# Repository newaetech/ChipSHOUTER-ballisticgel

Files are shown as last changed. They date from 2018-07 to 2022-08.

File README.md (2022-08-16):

# ChipSHOUTER® CW521 Ballistic Gel

The CW521 is an Electro-Magnetic Fault Injection (EMFI) target. It is specially designed to help you understand fault injection patterns for a given tip.

It uses a large SRAM chip as a target, which has a relatively simple layout. This lets you understand how much of a given chip you are corrupting.

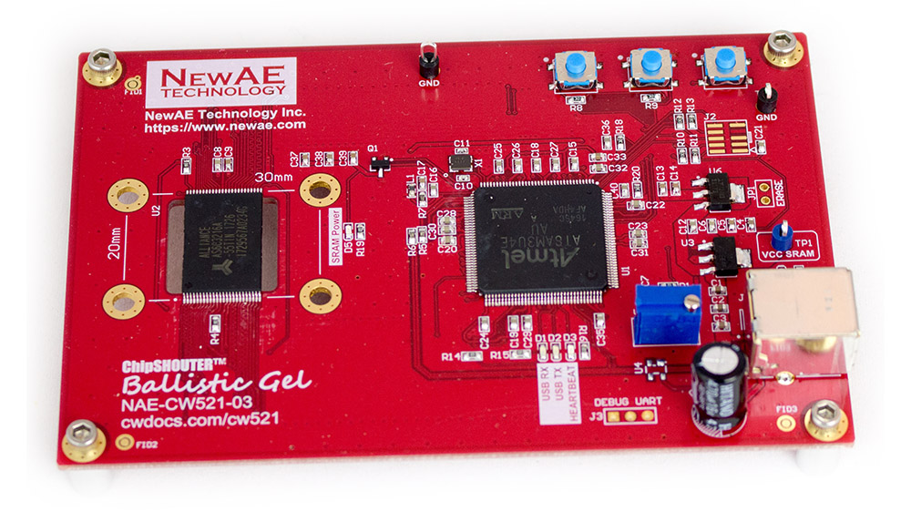
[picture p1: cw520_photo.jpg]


## GIT Layout ##

The GIT repository contains the following:

1) PCB source (Altium) + gerber files
2) Firmware for the microcontroller.
3) Python library / PC application.

## PC Application ##

The PC application is a simple example of using the Python library. This application does the following (via the library)

1. Downloads a pattern to the SRAM chip.
2. Waits for fault injection.
3. Uploads SRAM chip contents & determines corrupt locations.
4. Graphs map of physical SRAM locations (NB: not yet fully working).

The SRAM pattern can be something besides the random pattern, but the random pattern ensures "odd" corruptions (such as shorting address lines etc) will easily be caught.

An example of using the file is given at the end of ballisticgel.py, see the following:

	cw521 = CW521()
    cw521.con()
    
    doplot = False
    savefile = None
    #savefile = 'error_locations.bin' 
    
    #Raw method recommended - same speed and more flexible
    use_raw_method = True

    while True:
        try:        
            if use_raw_method:
                print "Writing data..."
                cw521.raw_test_setup()
                raw_input("Hit enter when glitch inserted")
                results = cw521.raw_test_compare()
            else:
                print "Writing data..."
                cw521.seed_test_setup()
                raw_input("Hit enter when glitch inserted")
                results = cw521.seed_test_compare()
            
            errdatay = results['errdatay']
            errdatax = results['errdatax']
            errorlist = results['errorlist']
            
            if doplot:
                plt.plot(errdatax, errdatay, '.r')
                plt.axis([0, 8192, 0, 4096])
                plt.show()

            if savefile:
                with open(savefile, "wb") as errfile:
                    errfile.write(bytearray(errorlist))
        except:
            cw521.close()

The "graph" that pops up afterwards is slightly bogus - the physical map of the SRAM is not yet accurate. But the most interesting aspect is that you can see number of bit flips (positive/negative), and total number of bytes corrupted.

### Result Format ###

The result information is provided in a dictionary. Depending if you use the fast (but less detailed) method or the slow (but more detailed) method you may not have all of these fields. It currently provides you with this:

 - 'errorlist': A list of addresses of each byte error. The length of this is the number of byte errors.
 - 'errdatax', 'errdatay': errdatax & errdatay attempt to provide a map of locations on SRAM chip where errors occurred. Until mapping is complete this is not fully accurate.
 - 'set_errors': Number of bit-set errors that occurred. Note number of bit errors is different from number of byte errors.
 - 'reset_errors': Number of bit-reset errors that occurred. Note number of bit errors is different from number of byte errors.

## Building Firmware ##

The firmware uses the ChipWhisperer capture build system (naeusb). Navigate to
`firmware/cw521` and run `git submodule update --init naeusb`. Once this has completed,
run `make`.

The firmware build requires `make` and `arm-none-eabi-gcc`.

## Drivers ##

As of commit f62ccdf0ea2d611deabf48ec3ad5db759205dbb0 and firmware version 2.0.0, 
the CW521 now uses the same WCID driver assignment as ChipWhisperer devices,
meaning no custom drivers need to be installed.

If you have old firmware/drivers and want to update, instructions
can be adapted from [ChipWhisperer's documentation on the subject](https://chipwhisperer.readthedocs.io/en/latest/drivers.html)

Note that the same `upgrade_firmware()` method is now available on the CW521 object:

```python
from ballisticgel import CW521
cw521 = CW521()
cw521.upgrade_firmware()
```

## Legal ##

Ballistic Gel is part of the ChipSHOUTER project (which is itself related to the ChipWhisperer project). It is also known as the CW521 target board.

Ballistic Gel is an open-source project, and is released with the GPL license. Assembled boards can be purchased from NewAE Technology Inc at https://store.newae.com .

ChipSHOUTER is a registered trademark of NewAE Technoloy Inc. Note you CANNOT sell boards using the ChipSHOUTER name without permission, and you cannot use NewAE Technology Inc's USB VID on your own products as the USB-IF license disallows sub-licensing in this manner. If you change the VID/PID, simply change the associated VID/PID in the .inf (driver) file as needed.

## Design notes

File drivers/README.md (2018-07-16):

# Driver Installation #

## Linux ##

 - Make a file called /etc/udev/rules.d/99-newae.rules . The contents of this file should be:
    ```
    #allow users to claim the device
    SUBSYSTEM=="usb", ATTRS{idVendor}=="2b3e", ATTRS{idProduct}=="ace1", MODE="0664", GROUP="plugdev"
    SUBSYSTEM=="usb", ATTRS{idVendor}=="2b3e", ATTRS{idProduct}=="ace2", MODE="0664", GROUP="plugdev" #CW-Lite
    SUBSYSTEM=="usb", ATTRS{idVendor}=="2b3e", ATTRS{idProduct}=="ace3", MODE="0664", GROUP="plugdev" #CW1200
    SUBSYSTEM=="usb", ATTRS{idVendor}=="2b3e", ATTRS{idProduct}=="c305", MODE="0664", GROUP="plugdev" #CW305 FPGA Target
    SUBSYSTEM=="usb", ATTRS{idVendor}=="2b3e", ATTRS{idProduct}=="c000", MODE="0664", GROUP="plugdev" #FTDI-Based JTAG Programmer
    SUBSYSTEM=="usb", ATTRS{idVendor}=="2b3e", ATTRS{idProduct}=="c521", MODE="0664", GROUP="plugdev" #CW521 Ballistic Gel
    ```
 - Add your username to the plugdev group:
    ```
    $ sudo usermod -a -G plugdev YOUR-USERNAME
    ```
 - And reset the udev system:
    ```
    $ sudo udevadm control --reload-rules
    ```

 - Finally log out & in again for the group change to take effect.

 - Connect the USB cable of your device.

## Windows ##

The attached USB drivers should work on any Windows system, both 32 and 64-bit. They are signed by NewAE Technology Inc.

We only store the **zip-file** in GIT, so you'll need to unzip it. This is done to avoid issues with line-ending changing causing the signatures to be invalid.

To install them:
 1. Unzip the zip-file somewhere. Also remember where.
 1. Open your Device Manager.
 1. Find the device in the list, it should appear with a yellow exclamation mark under "Other devices".
 1. Double-click on the device.
 1. Hit "Update Driver"
 1. Select "Browse my computer for driver software".
 1. Point the wizard to the folder you unzipped, ensure the "look in subfolders" option is selected.

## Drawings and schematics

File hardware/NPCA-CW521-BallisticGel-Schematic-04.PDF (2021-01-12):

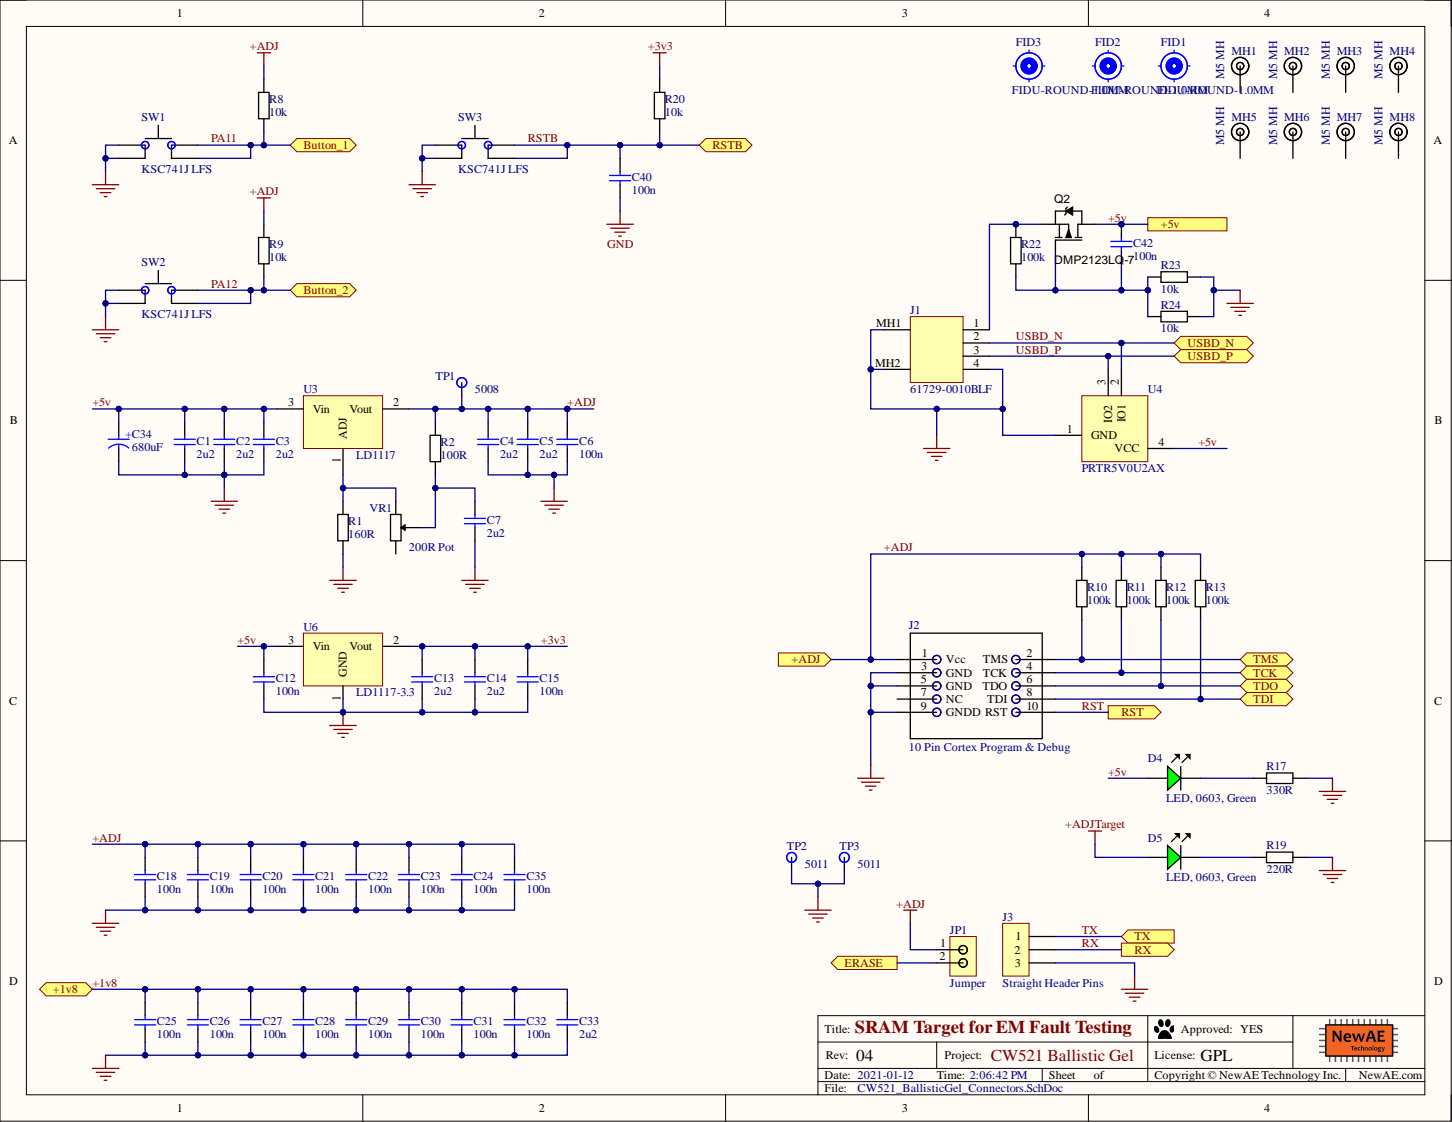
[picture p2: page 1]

10 Pin Cortex Program & Debug

SRAM Target forEM Fault Testing
Title:
Rev:
CW521_BallisticGel_Connectors.SchDoc

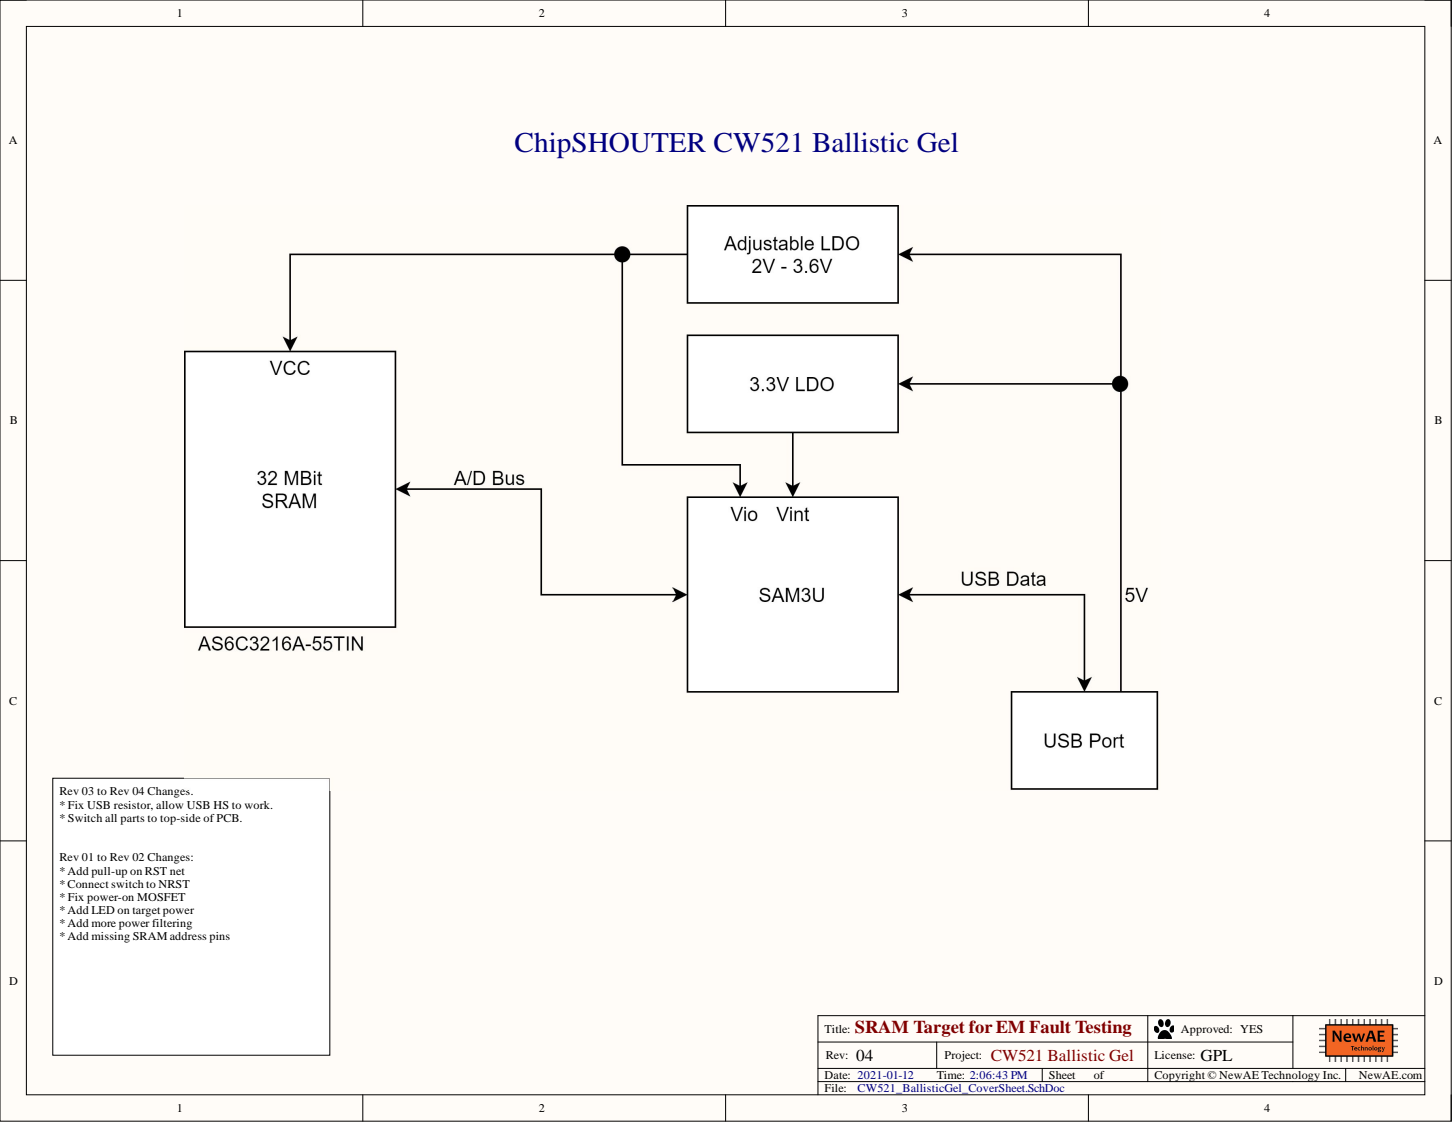
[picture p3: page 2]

Rev 03 to Rev 04 Changes:
* Fix USB resistor, allow USB HS to work.
* Switch all parts to top-side of PCB.

Rev 01 to Rev 02 Changes:
* Add pull-up on RST net
*Connectswitch to NRST
* Fix power-on MOSFET
* Add LED on target power
* Add more power filtering
* Add missing SRAM address pins

SRAM Target forEM Fault Testing

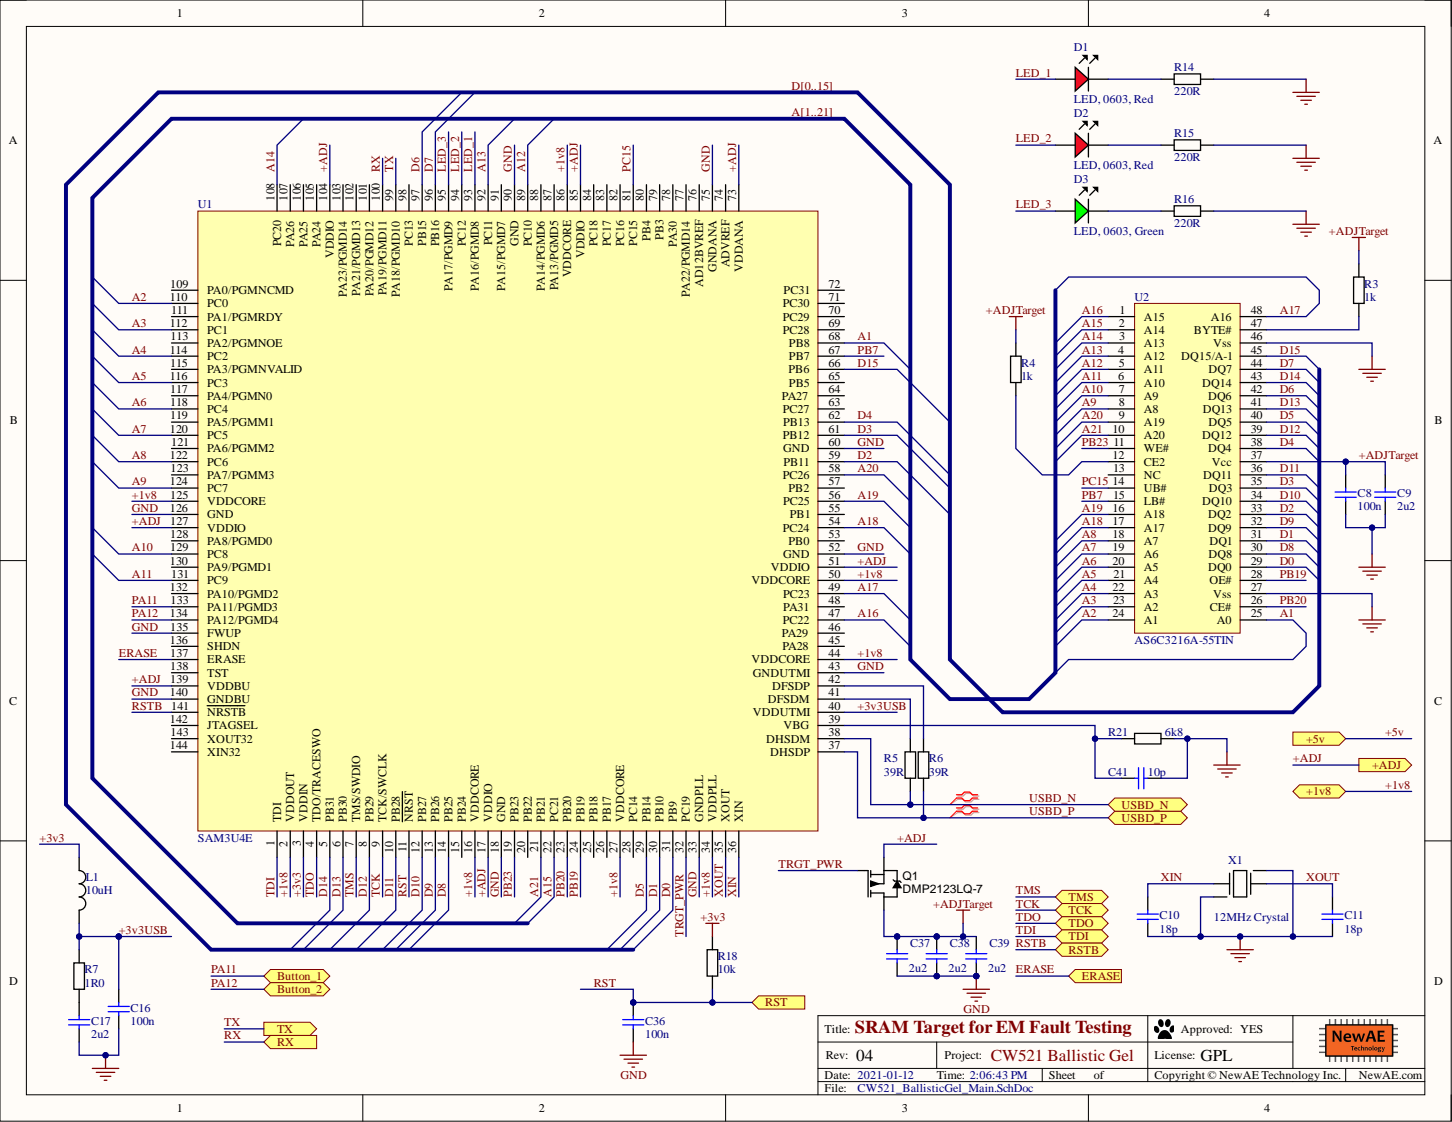
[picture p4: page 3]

VDDANA 73 ADVREF 74 GNDANA 75 AD12BVREF 76 PA22/PGMD14 77 PA30 78 PB3 79 PB4 80 PC15 81 PC16 82 PC17 83 PC18 84 VDDIO 85 VDDCORE 86 PA13/PGMD5 87 PA14/PGMD6 88 PC10 89 GND 90 PA15/PGMD7 91 PC11 92 PA16/PGMD8 93 PC12 94 PA17/PGMD9 95 PB16 96 PB15 97 PC13 98 PA18/PGMD10 99 PA19/PGMD11 100 PA20/PGMD12 101 PA21/PGMD13 102 PA23/PGMD14 103 VDDIO 104 PA24 105 PA25 106 PA26 107 PC20 108

SRAM Target forEM Fault Testing

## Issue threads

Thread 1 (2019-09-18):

python script error when reading back SRAM

doegox, 2019-09-18:
Trying the script, loading SRAM to the board worked fine, pressing Enter (without even EMFI), getting this error
```
ChipSHOUTER-ballisticgel/ballisticgel$ python ballisticgel.py
 CW521 Ballistic Gel Example Script
  by NewAE Technology Inc
 This script will continue until you exit with Ctrl-C
Settings:
  Using slow (raw) mode  : True
  Showing plot of results: False
  Results filename       : None
Starting main loop now:

LOOP START: Writing data to SRAM...
 Hit enter when glitch inserted
 Reading SRAM data...
Traceback (most recent call last):
  File "ballisticgel.py", line 329, in <module>
    results = cw521.raw_test_compare()
  File "ballisticgel.py", line 243, in raw_test_compare
    din = cw521.read_pattern()
  File "ballisticgel.py", line 102, in read_pattern
    din = self.usb.cmdReadMem(start_addr, len_to_read)
  File "/home/qb/00hardware_guilde/haqerspace/tools/chipshouter/ChipSHOUTER-ballisticgel/ballisticgel/naeusb.py", line 228, in cmdReadMem
    data = self.usbdev().read(self.rep, dlen, timeout=self._timeout)
  File "/home/phil/.local/lib/python2.7/site-packages/usb/core.py", line 988, in read
    self.__get_timeout(timeout))
  File "/home/phil/.local/lib/python2.7/site-packages/usb/backend/libusb0.py", line 542, in bulk_read
    timeout)
  File "/home/phil/.local/lib/python2.7/site-packages/usb/backend/libusb0.py", line 627, in __read
    timeout
  File "/home/phil/.local/lib/python2.7/site-packages/usb/backend/libusb0.py", line 431, in _check
    raise USBError(errmsg, ret)
usb.core.USBError: [Errno None] Connection timed out
```

colinoflynn, 2019-09-18:
Odd! We run that exact script as part of the test so the board HW *should* be fine... but I suspect it's some unknown compatibility problem.

What's your host OS?

doegox, 2019-09-18:
Linux, Debian 10.0 kernel 4.20
I poked around, if I set a large timeout on naeusb.py", line 228, the script doesn't crash but I get absurd results:
```
 Reading SRAM data...
Byte errors: 4178047 (of 4194304). Bit errors: 8387684 set (0 --> 1), 8387695 reset (1 --> 0)
```

Note that on the board, USB RX is steadily red for a while while SRAM gets loaded, but USB TX flashes only very briefly when SRAM gets read back.
So it seems that it's really the board that doesn't send much data back.

colinoflynn, 2019-09-18:
IIRC The USB TX led direction is a bit of a "bug"... the TX led gets set internally when the read-back starts, but the rest is done via DMA and it's no longer calling the USB routines for every transaction.

Also you can try switching between the "fast" and "complete" mode to see if it changes things. I'm going to try and recreate here on a Linux machine, our test machine was Windows I admit so I could have missed something there.

doegox, 2019-09-18:
about "large timeout on naeusb.py", line 228", here are some effects depending on the injected timeout:
* 0..4000 -> error
* 5000 -> absurd results, as shown above
* 6000 -> results that make sense (0 bitflip, more bitflip when EMFI)

doegox, 2019-09-18:
`use_raw_method = False` => works fine without hacking the timeout.

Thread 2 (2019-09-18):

Linux: better error handling when USB permissions problem

doegox, 2019-09-18:
On Linux, if someone forgets to install or update his /etc/udev/rules.d/99-newae.rules to include the ballisticgel VID:PID (hey what did you expect? ;) ), the python script fails with:
```
ValueError: The device has no langid
```
The error is not really helpful for someone to understand the root of the problem and the solution.
Example:
```diff
--- a/ballisticgel/naeusb.py
+++ b/ballisticgel/naeusb.py
@@ -109,7 +109,10 @@ class NAEUSB(object):
         """

         devlist = self.get_possible_devices(idProduct)
-        snlist = [d.serial_number + " (" + d.product + ")\n" for d in devlist]
+        try:
+            snlist = [d.serial_number + " (" + d.product + ")\n" for d in devlist]
+        except ValueError:
+            raise IOError("Check permissions to access the USB device")
         snlist = "".join(snlist)

```

```
$
python ballisticgel.py
 CW521 Ballistic Gel Example Script
  by NewAE Technology Inc
 This script will continue until you exit with Ctrl-C
Traceback (most recent call last):
  File "ballisticgel.py", line 306, in <module>
    cw521.con()
  File "ballisticgel.py", line 51, in con
    self.usb.con(idProduct=[usb_pid])
  File "/home/qb/00hardware_guilde/haqerspace/tools/chipshouter/ChipSHOUTER/ChipSHOUTER-ballisticgel/ballisticgel/naeusb.py", line 115, in con
    raise IOError("Check permissions to access the USB device")
IOError: Check permissions to access the USB device
```

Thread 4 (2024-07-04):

Issue calling the function usbdev() printing "Do not call me"

axelatsec, 2024-07-04:
When running ballisticgel.py in rng mode the return statement of the read function is this:

`return self.usb.usbdev().read(self.usb.rep, size, timeout=self.usb._timeout)`

and `self.usb.usbdev()` is not supposed to be called according to the function then printing "Do not call me". The code then stops functioning and doesn't complete the memory read.

alex-dewar, 2024-07-09:
Thanks for bringing this up. I'll get that fixed up.

Closed 2025-06-23.

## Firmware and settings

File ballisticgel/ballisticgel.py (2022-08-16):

# Copyright (c) 2018-2019, NewAE Technology Inc
# All rights reserved.
#
# Authors: Colin O'Flynn, Alex Dewar
#
# This file is part of the ChipSHOUTER Ballistic Gel project.
#
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
#    You should have received a copy of the GNU General Public License
#    along with this project.  If not, see <http://www.gnu.org/licenses/>.
#=============================================================================

import random

import numpy as np
import matplotlib.mlab as mlab
import matplotlib.pyplot as plt
from .ChipWhispererSAM3Update import SAMFWLoader, get_at91_ports

from . import srammap
from . import naeusb as NAE
import time
from typing import Optional, Type, Union

def program_sam_firmware(serial_port : Optional[str]=None,
    hardware_type : Optional[str]=None, fw_path : Optional[str]=None):
    """Program firmware onto an erased chipwhisperer scope or target

    See https://chipwhisperer.readthedocs.io/en/latest/firmware.html for more information

    .. versionadded:: 5.6.1
        Improved programming interface
    """
    if (hardware_type, fw_path) == (None, None):
        raise ValueError("Must specify hardware_type or fw_path, see https://chipwhisperer.readthedocs.io/en/latest/firmware.html")

    if serial_port is None:
        at91_ports = get_at91_ports()
        if len(at91_ports) == 0:
            raise OSError("Could not find bootloader serial port, please see https://chipwhisperer.readthedocs.io/en/latest/firmware.html")
        if len(at91_ports) > 1:
            raise OSError("Found multiple bootloaders, please specify com port. See https://chipwhisperer.readthedocs.io/en/latest/firmware.html")

        serial_port = at91_ports[0]
        print("Found {}".format(serial_port))
    prog = SAMFWLoader(None)
    prog.program(serial_port, hardware_type=hardware_type, fw_path=fw_path)


def packuint32(data):
    """Converts a 32-bit integer into format expected by USB firmware"""

    return [data & 0xff, (data >> 8) & 0xff, (data >> 16) & 0xff, (data >> 24) & 0xff]

class CW521(object):
    """This class defines communications with CW521 Ballistic Gel Target"""

    REQ_CHECKMEM_RNG = 0x15
    REQ_MEMWRITE_RNG = 0x14
    REQ_MEMREAD_RNG_BULK = 0x18

    sram_len = 4194304
    _hw_type = "cw521"

    def _getNAEUSB(self):
        return self.usb

    def _getCWType(self):
        return "cw521"

    def con(self, usb_vid=0x2B3E, usb_pid=0xC521):
        """Connect to the Ballistic Gel, use default VID/PID"""

        self.usb = NAE.NAEUSB()
        self.usb.con(idProduct=[usb_pid])

    def upgrade_firmware(self):
        prog = SAMFWLoader(self)
        prog.auto_program()

    def write_pattern(self, pattern):
        """Download an arbitrary pattern to the entire SRAM"""

        if len(pattern) > self.sram_len:
            raise ValueError("Length of pattern (%d) too long"%(len(pattern)))

        #Break into 1024 chunks on write - required to avoid buffer overflow!
        totalsent = 0
        chunksize = 1024
        self.usb.cmdWriteMem(0, pattern)

    def write_seed(self, seed, addr, length):
        """Write 'length' random data to 'addr', based on 'seed', done on-board
        the CW521 so faster than downloading a specific pattern.
        """
        if (len(seed) != 16):
            raise ValueError("Length of seed incorrect {}".format(len(seed)))
        pload = packuint32(length)
        pload.extend(packuint32(addr))
        pload.extend(seed)
        self.usb.sendCtrl(self.REQ_MEMWRITE_RNG, data=pload)


    def read_pattern(self, start_addr=0, len_to_read=None):
        """Read a block of data from SRAM."""

        if len_to_read is None:
            len_to_read = self.sram_len

        if len_to_read < 0:
            len_to_read = self.sram_len + len_to_read

        if (len_to_read + start_addr) > self.sram_len:
            raise ValueError("len_to_read (%d) is too long"%len_to_read)

        din = self.usb.cmdReadMem(start_addr, len_to_read)

        return din

    def read_pattern_rng(self, addr, size = 4096):
        """Read error pattern, assuming it was written using seed previously."""
        
        if size > 8192:
            raise ValueError("Read pattern too large")

        pload = packuint32(size)
        pload.extend(packuint32(addr))
        self.usb.sendCtrl(self.REQ_CHECKMEM_RNG, data=pload)
        data = self.usb.readCtrl(self.REQ_CHECKMEM_RNG, dlen = 4)
        reported_count = (data[3] << 8) | data[2]
        reported_count -= 1
        
        # Check if any errors reported - if not we return a null pattern array without needing to do
        # USB transfers at all
        if data[0] == 0:
            return [0] * size
        else:
            #Uncomment this to get details on-the-fly
            #print "Error in block {} ({}) (addr = {}, size = {})".format(addr / size, reported_count, addr, size)
            cmd = self.REQ_MEMREAD_RNG_BULK
            pload = packuint32(size)
            pload.extend(packuint32(addr))
            self.usb.sendCtrl(cmd, data=pload)
            return self.usb.usbdev().read(self.usb.rep, size, timeout=self.usb._timeout)

    def close(self):
        self.usb.close()


    def get_xor_sram(self, sram_len):
        data = np.random.randint(0, 256, sram_len)
        print("Generating xor")
        for i in range(sram_len / 4):
            if (not (i % 10000)):
                print("Done {}".format(i))
            rng_val = xorshift128()
            for j in range(4):
                data[i * 4 + j] = (rng_val >> (8 * j)) & 0xFF
        return data
               
    def seed_test_setup(self, seed=0xFAA2):
        """Setup the SRAM using a seed, target pattern generation is done on-device.
        After a fault is inserted, call seed_test_compare() to find fault numbers and
        locations."""
    
        state = []
        for i in range(0, 4):
            state.extend(packuint32(seed))
            
        self.block_size = 8192
        #time1 = time.clock()

        # Have to do one extra?
        for i in range(int(self.sram_len / self.block_size) + 1):
            self.write_seed(state, i * self.block_size, self.block_size)
        # self.write_pattern(data)
        #time2 = time.clock()
        #write_time = time2 - time1

        #Generate random test vector (so when re-run know if write was working)
        # print "Generating test vector %d bytes"%self.sram_len

        # time1 = time.clock()
        # data = get_xor_sram(self.sram_len)
        # time2 = time.clock()
        # pattern_time = time2 - time1
        
        
    def seed_test_compare(self):
        """Test the SRAM for faults, assuming it was previously setup with seed_test_setup()"""

        #time1 = time.clock()
        errorlist = []
        for i in range(0, int(self.sram_len / self.block_size)):
            errorlist.extend(self.read_pattern_rng(i * self.block_size, self.block_size))
        #time2 = time.clock()
        #read_time = time2 - time1

        test_len = self.sram_len
        #time1 = time.clock()
        byte_errors = 0
        for i in range(0, len(errorlist)):
            if not errorlist[i] == 0:
                byte_errors += 1

        #time2 = time.clock()
        #check_time = time2 - time1

        print("Byte errors: {}".format(byte_errors))
        #print "Write: {}, Read: {}, Check: {}".format(write_time, read_time, check_time)

        #print "Getting actual glitch locations in SRAM"
        sram = srammap.SRAMMapping()
        errdatax = []
        errdatay = []
        pone = False
        for i in range(0, 2**22, 2):
            err = errorlist[i] | errorlist[i + 1]

            if err > 0:
                locs = sram.get_bit_locations(i >> i)
                x = locs[0]
                ybitarray = locs[1]
                for bnum in range(0, 16):
                    if err & (1<<bnum):
                        errdatax.append(x)
                        errdatay.append(ybitarray[bnum])

        return {'errorlist':np.array(errorlist, dtype=np.uint8), 'errdatax':np.array(errdatax, dtype=np.uint8), 
                'errdatay':np.array(errdatay, dtype=np.uint8)}

    def raw_test_setup(self):
        """Download a raw pattern to the SRAM, slower than the seed method but
        allows arbitrary patterns. After inserting a fault test the pattern with
        raw_test_compare()"""

        #Generate random test vector (so when re-run know if write was working)
        #print "Generating test vector %d bytes"%self.sram_len

        #time1 = time.clock()
        self.data = np.random.randint(0, 256, self.sram_len, dtype=np.uint8)
        #time2 = time.clock()
        #pattern_time = time2 - time1

        #print "Writing..."
        #time1 = time.clock()
        self.write_pattern(self.data)
        #time2 = time.clock()
        #write_time = time2 - time1

        return
        
    def raw_test_compare(self):
        """Check the SRAM for faults based on a raw pattern previously downloaded
        with raw_test_setup()"""

        #time1 = time.clock()
        din = self.read_pattern()
        din = np.array(din, dtype=np.uint8)
        #time2 = time.clock()
        #read_time = time2 - time1

        errorcnt = 0

        errorlist = []
        set_errors = []
        reset_errors = []

        test_len = self.sram_len

        #time1 = time.clock()
        diff_list = self.data ^ din

        def np_hamming(arr):
            hw_arr = np.zeros(np.shape(arr), dtype=np.uint8)
            for i in range(8):
                hw_arr += (arr & (1 << i)) >> i
            return hw_arr

        errorlist = np_hamming(diff_list)
        set_errors = np_hamming(diff_list & ~self.data)
        reset_errors = np_hamming(diff_list & self.data)
            
        # for i in range(0, test_len):
        #     if self.data[i] != din[i]:

        #         diff = self.data[i] ^ din[i]
        #         errorlist.append(bin(diff).count('1'))
        #         set_errors.append(bin(diff & self.data[i]).count('1'))
        #         reset_errors.append(bin(diff & ~self.data[i]).count('1'))
        #         if bin(diff & ~self.data[i]).count('1') > 8:
        #             print("BULLSHIT DETECTED")
        #         errorcnt += 1
        #     else:
        #         errorlist.append(0)
        #time2 = time.clock()
        #check_time = time2 - time1

        total_set_errors = np.sum(set_errors, dtype=np.uint32)
        total_reset_errors = np.sum(reset_errors, dtype=np.uint32)

        print("Byte errors: %d (of %d). Bit errors: %d set (0 --> 1), %d reset (1 --> 0)"%(errorcnt, test_len, total_set_errors, total_reset_errors))
        #print " Timing: pattern: {}, Write: {}, Read: {}, Check: {}".format(pattern_time, write_time, read_time, check_time)

        errdatax = []
        errdatay = []
        if errorcnt > 0:
            sram = srammap.SRAMMapping()
            pone = False

            for i in range(0, 2**22, 2):
                err = errorlist[i] | errorlist[i + 1]
                if err > 0:
                    #SAM3U to SRAM mapping has A1 mapped to A0 etc, so need to account
                    #for addressing used here
                    locs = sram.get_bit_locations(i >> 1)
                    x = locs[0]
                    ybitarray = locs[1]

                    for bnum in range(0, 16):
                        if err & (1<<bnum):
                            errdatax.append(x)
                            errdatay.append(ybitarray[bnum])


        return {'errorlist':errorlist, 'errdatax':errdatax, 'errdatay':errdatay, 'set_errors':set_errors, 'reset_errors':reset_errors}

if __name__ == "__main__":

    print(" CW521 Ballistic Gel Example Script ")
    print("  by NewAE Technology Inc")
    print(" This script will continue until you exit with Ctrl-C")
    
    cw521 = CW521()
    cw521.con()
    
    doplot = False
    savefile = None
    #savefile = 'error_locations.bin' 
    
    #Raw method is slower but more flexible
    use_raw_method = False

    print("Settings: ")
    print("  Using slow (raw) mode  : " + str(use_raw_method))
    print("  Showing plot of results: " + str(doplot))
    print("  Results filename       : " + str(savefile))

    print("Starting main loop now: \n")
    
    while True:
        try:        
            if use_raw_method:
                print("LOOP START: Writing data to SRAM...")
                cw521.raw_test_setup()
                input(" Hit enter when glitch inserted")
                print(" Reading SRAM data...")
                results = cw521.raw_test_compare()
            else:
                print("LOOP START: Writing data to SRAM...")
                cw521.seed_test_setup()
                input(" Hit enter when glitch inserted")
                print(" Reading SRAM data...")
                results = cw521.seed_test_compare()
            
            errdatay = results['errdatay']
            errdatax = results['errdatax']
            errorlist = results['errorlist']
            
            if doplot:
                plt.plot(errdatax, errdatay, '.r')
                plt.axis([0, 8192, 0, 4096])
                plt.show()

            if savefile:
                with open(savefile, "wb") as errfile:
                    errfile.write(bytearray(errorlist))

            print("")
        
        except:
            cw521.close()
            raise

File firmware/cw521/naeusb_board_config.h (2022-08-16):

/**
 * \file
 *
 * \brief SAM3U-EK Board Definition.
 *
 * Copyright (c) 2011 - 2013 Atmel Corporation. All rights reserved.
 *
 * \asf_license_start
 *
 * \page License
 *
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
 * 3. The name of Atmel may not be used to endorse or promote products derived
 *    from this software without specific prior written permission.
 *
 * 4. This software may only be redistributed and used in connection with an
 *    Atmel microcontroller product.
 *
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
 * \asf_license_stop
 *
 */

#ifndef _SAM3U_EK_H_
#define _SAM3U_EK_H_

#include "compiler.h"
#include "system_sam3u.h"
#include "exceptions.h"

/*----------------------------------------------------------------------------*/
/**
 *  \page sam3u_ek_opfreq SAM3U-EK - Operating frequencies
 *  This page lists several definition related to the board operating frequency
 *
 *  \section Definitions
 *  - \ref BOARD_FREQ_*
 *  - \ref BOARD_MCK
 */

/** Board oscillator settings */
#define BOARD_FREQ_SLCK_XTAL        (0U)
#define BOARD_FREQ_SLCK_BYPASS      (0U)
#define BOARD_FREQ_MAINCK_XTAL      (12000000U)
#define BOARD_FREQ_MAINCK_BYPASS    (12000000U)

/** Master clock frequency */
#define BOARD_MCK                   CHIP_FREQ_CPU_MAX

/** board main clock xtal startup time */
#define BOARD_OSC_STARTUP_US   15625

/*----------------------------------------------------------------------------*/
/**
 * \page sam3u_ek_board_info SAM3U-EK - Board informations
 * This page lists several definition related to the board description.
 *
 * \section Definitions
 * - \ref BOARD_NAME
 * - \ref sam3uek
 * - \ref sam3u
 * - \ref cortexm3
 */

/** Name of the board */
#define BOARD_NAME "ChipWhisperer-CW521"
/** Board definition */
#define cw521
/** Family definition (already defined) */
#define sam3u
/** Core definition */
#define cortexm3

/*----------------------------------------------------------------------------*/
//! Pins ADC
#define PINS_ADC12B_TRIG  PIO_PA2_IDX
#define PINS_ADC12B_TRIG_FLAG  (PIO_PERIPH_B | PIO_DEFAULT)
#define PINS_ADC_TRIG  PIO_PA17_IDX
#define PINS_ADC_TRIG_FLAG  (PIO_PERIPH_B | PIO_DEFAULT)

//! UART pins (UTXD0 and URXD0) definitions, PA9,10.
#define PINS_UART       (PIO_PA11A_URXD | PIO_PA12A_UTXD)
#define PINS_UART_FLAGS (PIO_PERIPH_A | PIO_DEFAULT)

#define PINS_UART_MASK PIO_PA11A_URXD|PIO_PA12A_UTXD
#define PINS_UART_PIO PIOA
#define PINS_UART_ID ID_PIOA
#define PINS_UART_TYPE PIO_PERIPH_A
#define PINS_UART_ATTR PIO_DEFAULT

#define FPGA_ALE_GPIO		 (PIO_PB21_IDX)
#define FPGA_ALE_FLAGS		 (PIO_TYPE_PIO_OUTPUT_1 | PIO_DEFAULT)

/** EBI Data Bus pins */
#define PIN_EBI_DATA_BUS_D0        PIO_PB9_IDX
#define PIN_EBI_DATA_BUS_D1        PIO_PB10_IDX
#define PIN_EBI_DATA_BUS_D2        PIO_PB11_IDX
#define PIN_EBI_DATA_BUS_D3        PIO_PB12_IDX
#define PIN_EBI_DATA_BUS_D4        PIO_PB13_IDX
#define PIN_EBI_DATA_BUS_D5        PIO_PB14_IDX
#define PIN_EBI_DATA_BUS_D6        PIO_PB15_IDX
#define PIN_EBI_DATA_BUS_D7        PIO_PB16_IDX
#define PIN_EBI_DATA_BUS_D8        PIO_PB25_IDX
#define PIN_EBI_DATA_BUS_D9        PIO_PB26_IDX
#define PIN_EBI_DATA_BUS_D10        PIO_PB27_IDX
#define PIN_EBI_DATA_BUS_D11        PIO_PB28_IDX
#define PIN_EBI_DATA_BUS_D12        PIO_PB29_IDX
#define PIN_EBI_DATA_BUS_D13        PIO_PB30_IDX
#define PIN_EBI_DATA_BUS_D14        PIO_PB31_IDX
#define PIN_EBI_DATA_BUS_D15        PIO_PB6_IDX

#define PIN_EBI_DATA_BUS_FLAG1   PIO_PERIPH_A | PIO_PULLUP
#define PIN_EBI_DATA_BUS_FLAG2   PIO_PERIPH_B | PIO_PULLUP

/* NBS0 = A0 = LB# */
/* NBS1      = UB# */
#define PIN_EBI_ADDR_BUS_NBS0 PIO_PB7_IDX
#define PIN_EBI_ADDR_BUS_NBS1 PIO_PC15_IDX

#define PIN_EBI_ADDR_BUS_FLAG1  PIO_PERIPH_B | PIO_PULLUP
#define PIN_EBI_ADDR_BUS_FLAG2  PIO_PERIPH_A | PIO_PULLUP

#define PIN_EBI_ADDR_BUS_A0        PIO_PB7_IDX
#define PIN_EBI_ADDR_BUS_A1        PIO_PB8_IDX
#define PIN_EBI_ADDR_BUS_A2        PIO_PC0_IDX
#define PIN_EBI_ADDR_BUS_A3        PIO_PC1_IDX
#define PIN_EBI_ADDR_BUS_A4        PIO_PC2_IDX
#define PIN_EBI_ADDR_BUS_A5        PIO_PC3_IDX
#define PIN_EBI_ADDR_BUS_A6        PIO_PC4_IDX
#define PIN_EBI_ADDR_BUS_A7        PIO_PC5_IDX
#define PIN_EBI_ADDR_BUS_A8        PIO_PC6_IDX
#define PIN_EBI_ADDR_BUS_A9        PIO_PC7_IDX
#define PIN_EBI_ADDR_BUS_A10       PIO_PC8_IDX
#define PIN_EBI_ADDR_BUS_A11       PIO_PC9_IDX
#define PIN_EBI_ADDR_BUS_A12       PIO_PC10_IDX
#define PIN_EBI_ADDR_BUS_A13       PIO_PC11_IDX
#define PIN_EBI_ADDR_BUS_A14       PIO_PC20_IDX
#define PIN_EBI_ADDR_BUS_A15       PIO_PC21_IDX
#define PIN_EBI_ADDR_BUS_A16       PIO_PC22_IDX
#define PIN_EBI_ADDR_BUS_A17       PIO_PC23_IDX
#define PIN_EBI_ADDR_BUS_A18       PIO_PC24_IDX
#define PIN_EBI_ADDR_BUS_A19       PIO_PC25_IDX
#define PIN_EBI_ADDR_BUS_A20       PIO_PC26_IDX
#define PIN_EBI_ADDR_BUS_A21       PIO_PB21_IDX

#define FPGA_ADDR_PINS (PIO_PB0 | PIO_PB1 | PIO_PB2 | PIO_PB3 | PIO_PB4 | PIO_PB5 | PIO_PB6 | PIO_PB7 )
#define FPGA_ADDR_PORT PIOB
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

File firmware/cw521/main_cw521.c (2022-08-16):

/*
 Copyright (C) 2018 NewAE Technology Inc. All Rights Reserved.

  This file is part of the CW522 Ballistic Gel Project.

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

 */

#include <asf.h>
#include "conf_usb.h"
#include "stdio_serial.h"
#include "ui.h"
#include "genclk.h"
#include "tasks.h"
#include "usb.h"
#include "sysclk.h"
#include "naeusb/naeusb_default.h"
#include "naeusb/naeusb.h"
#include "naeusb_ballistic.h"
#include "naeusb/usb_xmem.h"
#include <string.h>


//Serial Number - will be read by device ID
char usb_serial_number[33] = "000000000000DEADBEEF";

static void configure_console(void);

/*! \brief Main function. Execution starts here.
 */
int main(void)
{
  uint32_t serial_number[4];

  // Read Device-ID from SAM3U. Do this before enabling interrupts etc.
  flash_read_unique_id(serial_number, sizeof(serial_number));

  configure_console();

  irq_initialize_vectors();
  cpu_irq_enable();

  // Initialize the sleep manager
  sleepmgr_init();
#if !SAMD21 && !SAMR21
  sysclk_init();
  board_init();
#else
  system_init();
#endif

  //Convert serial number to ASCII for USB Serial number
  for(unsigned int i = 0; i < 4; i++){
    sprintf(usb_serial_number+(i*8), "%08x", (unsigned int)serial_number[i]);
  }
  usb_serial_number[32] = 0;

  printf("ChipSHOUTER C521 Ballistic Gel Online. Firmware build: %s/%s\n", __TIME__, __DATE__);
  printf("Serial number: %s\n", usb_serial_number);


  /* Enable SMC */
  pmc_enable_periph_clk(ID_SMC);
  gpio_configure_pin(PIN_EBI_DATA_BUS_D0, PIN_EBI_DATA_BUS_FLAG1);
  gpio_configure_pin(PIN_EBI_DATA_BUS_D1, PIN_EBI_DATA_BUS_FLAG1);
  gpio_configure_pin(PIN_EBI_DATA_BUS_D2, PIN_EBI_DATA_BUS_FLAG1);
  gpio_configure_pin(PIN_EBI_DATA_BUS_D3, PIN_EBI_DATA_BUS_FLAG1);
  gpio_configure_pin(PIN_EBI_DATA_BUS_D4, PIN_EBI_DATA_BUS_FLAG1);
  gpio_configure_pin(PIN_EBI_DATA_BUS_D5, PIN_EBI_DATA_BUS_FLAG1);
  gpio_configure_pin(PIN_EBI_DATA_BUS_D6, PIN_EBI_DATA_BUS_FLAG1);
  gpio_configure_pin(PIN_EBI_DATA_BUS_D7, PIN_EBI_DATA_BUS_FLAG1);
  gpio_configure_pin(PIN_EBI_DATA_BUS_D8, PIN_EBI_DATA_BUS_FLAG1);
  gpio_configure_pin(PIN_EBI_DATA_BUS_D9, PIN_EBI_DATA_BUS_FLAG1);
  gpio_configure_pin(PIN_EBI_DATA_BUS_D10, PIN_EBI_DATA_BUS_FLAG1);
  gpio_configure_pin(PIN_EBI_DATA_BUS_D11, PIN_EBI_DATA_BUS_FLAG1);
  gpio_configure_pin(PIN_EBI_DATA_BUS_D12, PIN_EBI_DATA_BUS_FLAG1);
  gpio_configure_pin(PIN_EBI_DATA_BUS_D13, PIN_EBI_DATA_BUS_FLAG1);
  gpio_configure_pin(PIN_EBI_DATA_BUS_D14, PIN_EBI_DATA_BUS_FLAG1);
  gpio_configure_pin(PIN_EBI_DATA_BUS_D15, PIN_EBI_DATA_BUS_FLAG2);
  gpio_configure_pin(PIN_EBI_NRD, PIN_EBI_NRD_FLAGS);
  gpio_configure_pin(PIN_EBI_NWE, PIN_EBI_NWE_FLAGS);
  gpio_configure_pin(PIN_EBI_NCS0, PIN_EBI_NCS0_FLAGS);

  gpio_configure_pin(PIN_EBI_ADDR_BUS_NBS0, PIN_EBI_ADDR_BUS_FLAG1);
  gpio_configure_pin(PIN_EBI_ADDR_BUS_NBS1, PIN_EBI_ADDR_BUS_FLAG2);

  gpio_configure_pin(PIN_EBI_ADDR_BUS_A1, PIN_EBI_ADDR_BUS_FLAG1);
  gpio_configure_pin(PIN_EBI_ADDR_BUS_A2, PIN_EBI_ADDR_BUS_FLAG2);
  gpio_configure_pin(PIN_EBI_ADDR_BUS_A3, PIN_EBI_ADDR_BUS_FLAG2);
  gpio_configure_pin(PIN_EBI_ADDR_BUS_A4, PIN_EBI_ADDR_BUS_FLAG2);
  gpio_configure_pin(PIN_EBI_ADDR_BUS_A5, PIN_EBI_ADDR_BUS_FLAG2);
  gpio_configure_pin(PIN_EBI_ADDR_BUS_A6, PIN_EBI_ADDR_BUS_FLAG2);
  gpio_configure_pin(PIN_EBI_ADDR_BUS_A7, PIN_EBI_ADDR_BUS_FLAG2);
  gpio_configure_pin(PIN_EBI_ADDR_BUS_A8, PIN_EBI_ADDR_BUS_FLAG2);
  gpio_configure_pin(PIN_EBI_ADDR_BUS_A9, PIN_EBI_ADDR_BUS_FLAG2);
  gpio_configure_pin(PIN_EBI_ADDR_BUS_A10, PIN_EBI_ADDR_BUS_FLAG2);
  gpio_configure_pin(PIN_EBI_ADDR_BUS_A11, PIN_EBI_ADDR_BUS_FLAG2);
  gpio_configure_pin(PIN_EBI_ADDR_BUS_A12, PIN_EBI_ADDR_BUS_FLAG2);
  gpio_configure_pin(PIN_EBI_ADDR_BUS_A13, PIN_EBI_ADDR_BUS_FLAG2);
  gpio_configure_pin(PIN_EBI_ADDR_BUS_A14, PIN_EBI_ADDR_BUS_FLAG2);
  gpio_configure_pin(PIN_EBI_ADDR_BUS_A15, PIN_EBI_ADDR_BUS_FLAG2);
  gpio_configure_pin(PIN_EBI_ADDR_BUS_A16, PIN_EBI_ADDR_BUS_FLAG2);
  gpio_configure_pin(PIN_EBI_ADDR_BUS_A17, PIN_EBI_ADDR_BUS_FLAG2);
  gpio_configure_pin(PIN_EBI_ADDR_BUS_A18, PIN_EBI_ADDR_BUS_FLAG2);
  gpio_configure_pin(PIN_EBI_ADDR_BUS_A19, PIN_EBI_ADDR_BUS_FLAG2);
  gpio_configure_pin(PIN_EBI_ADDR_BUS_A20, PIN_EBI_ADDR_BUS_FLAG2);
  gpio_configure_pin(PIN_EBI_ADDR_BUS_A21, PIN_EBI_ADDR_BUS_FLAG2);

  /* Configure EBI I/O for PSRAM connection */
  printf("Setting up SRAM Communication\n");

  /* complete SMC configuration between PSRAM and SMC waveforms. */
  /*
  smc_set_setup_timing(SMC, 0, SMC_SETUP_NWE_SETUP(0)
  | SMC_SETUP_NCS_WR_SETUP(2)
  | SMC_SETUP_NRD_SETUP(2)
  | SMC_SETUP_NCS_RD_SETUP(2));
  smc_set_pulse_timing(SMC, 0, SMC_PULSE_NWE_PULSE(6)
  | SMC_PULSE_NCS_WR_PULSE(6)
  | SMC_PULSE_NRD_PULSE(6)
  | SMC_PULSE_NCS_RD_PULSE(6));
  smc_set_cycle_timing(SMC, 0, SMC_CYCLE_NWE_CYCLE(8)
  | SMC_CYCLE_NRD_CYCLE(8));
  smc_set_mode(SMC, 0, SMC_MODE_READ_MODE_NRD_CTRL | SMC_MODE_WRITE_MODE_NWE_CTRL
  | SMC_MODE_DBW_BIT_16);
  */

    smc_set_setup_timing(SMC, 0, SMC_SETUP_NWE_SETUP(0)
    | SMC_SETUP_NCS_WR_SETUP(4)
    | SMC_SETUP_NRD_SETUP(4)
    | SMC_SETUP_NCS_RD_SETUP(4));
    smc_set_pulse_timing(SMC, 0, SMC_PULSE_NWE_PULSE(12)
    | SMC_PULSE_NCS_WR_PULSE(12)
    | SMC_PULSE_NRD_PULSE(12)
    | SMC_PULSE_NCS_RD_PULSE(12));
    smc_set_cycle_timing(SMC, 0, SMC_CYCLE_NWE_CYCLE(16)
    | SMC_CYCLE_NRD_CYCLE(16));
    smc_set_mode(SMC, 0, SMC_MODE_READ_MODE_NRD_CTRL | SMC_MODE_WRITE_MODE_NWE_CTRL
    | SMC_MODE_DBW_BIT_16);

  /*
  osc_enable(OSC_MAINCK_XTAL);
      osc_wait_ready(OSC_MAINCK_XTAL);
      pmc_switch_mck_to_mainck(CONFIG_SYSCLK_PRES);
  */
  ui_init();

  // Start USB stack to authorize VBus monitoring
  udc_start();

  printf("Event Loop Entered, waiting...\n");

  // The main loop manages only the power mode
  // because the USB management is done by interrupt
	naeusb_register_handlers();
  ballistic_register_handlers();
  while (true) {
    // sleepmgr_enter_sleep();
  }
}

/**
 *  Configure UART console.
 */
static void configure_console(void)
{
  const usart_serial_options_t uart_serial_options = {
    .baudrate = CONF_UART_BAUDRATE,
    .paritytype = CONF_UART_PARITY
  };

  /* Configure console UART. */
  sysclk_enable_peripheral_clock(CONSOLE_UART_ID);
  stdio_serial_init(CONF_UART, &uart_serial_options);
}

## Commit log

2017-12-05 FW: Fix to make working
    [cw521.h, main_cw521.c, usb.c]
2018-01-02 *Update firmware with LEDs
    *Split Python example into two classes
2018-03-21 Added HAL
    [Makefile.hal]
2018-03-23 Fixed unrng'd memory in final sram block
    [ballisticgel.py, usb.c]
2018-06-19 Move previous hal build into main firmware directory, remove AS project (will re-add)
    [Makefile.hal]
2018-06-20 Fix firmware when using old read/write
    [main_cw521.c, usb.c]
2018-06-20 Python fixes, starting to add minor docs
    [ballisticgel.py]
2018-07-16 Fix build, change USB PID to unique value.
    [main_cw521.c, ui_cw305.c]
2018-07-16 Add windows drivers
2018-07-16 Update python script to work with new VID/PID
2020-10-08 Fix cw521 reference internally
    [ballisticgel.py]
2021-01-12 Add schematic that has been missing since birth!
2022-03-08 Compiles, connects, sram errors
    [Makefile.hal]
2022-05-19 Add PCBs
    [CW521_BallisticGel.PrjPcb, CW521_BallisticGel_Connectors.SchDoc, CW521_BallisticGel_CoverSheet.SchDoc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]
2022-08-16 bump version, update readme with new driver info
2022-08-16 Fix set/reset errors being inverted
    [ballisticgel.py]

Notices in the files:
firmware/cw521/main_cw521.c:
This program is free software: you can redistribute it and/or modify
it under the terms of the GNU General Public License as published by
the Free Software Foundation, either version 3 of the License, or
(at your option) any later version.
